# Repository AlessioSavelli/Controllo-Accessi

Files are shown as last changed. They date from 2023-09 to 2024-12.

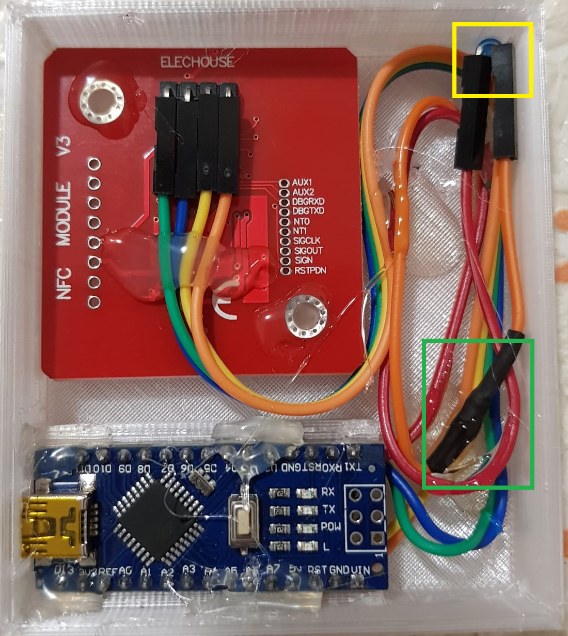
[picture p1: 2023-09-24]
Firmware/Relese/Interfaccia Software/Montaggio.png

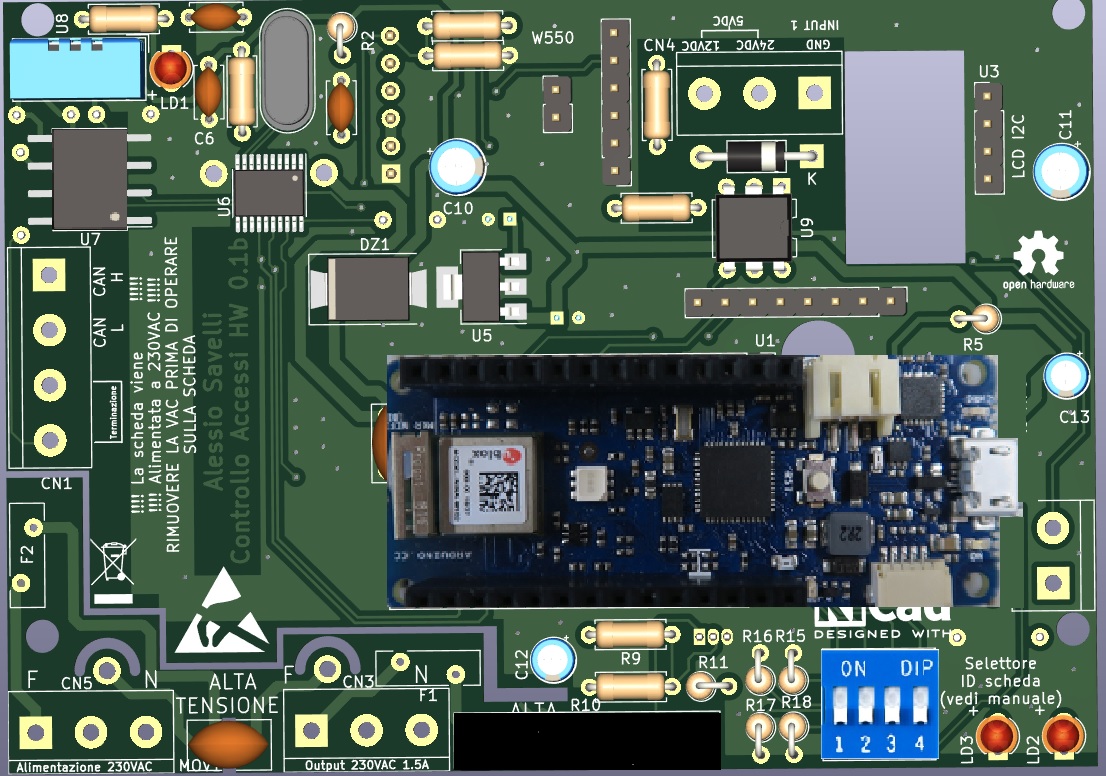
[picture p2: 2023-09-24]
Hardware/Schema Montaggio Attivatore/Immagine WhatsApp 2023-09-23 ore 09.59.53.jpg

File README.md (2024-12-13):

# Controllo Accessi  
 Controllo Accessi realizzato con arduino mkr 1010 e visual studio.

In questa sezione troverai tutti i sorgenti Hardware, Software e Firmware per creare e utilizzare il tuo allarmino.

I Firmware disponibili per Arduino MKR 1010 sono:
<table class="tg">
<thead>
  <tr>
    <th class="tg-0pky">Firmware</th>
  </tr>
</thead>
<tbody>
  <tr>
    <td class="tg-0pky">V1.0</td>
  </tr>
</tbody>
</table>
  
I Software disponibili :
  <table class="tg">
<thead>
  <tr>
    <th class="tg-0lax">Software</th>
    <th class="tg-0pky">Testato su</th>
  </tr>
</thead>
<tbody>
  <tr>
    <td class="tg-0lax">V1.0</td>
    <td class="tg-0pky">Win10 64-bit, Win 11 64-bit</td>
  </tr>
</tbody>
</table>
  
Gli Hardware disponibili :
<table class="tg">
<thead>
  <tr>
    <td class="tg-0lax">Controllo Accessi Main Board</td>
    <td class="tg-0pky">Interfaccia di scrittura badge con Arduino Mini</td>
  </tr>
</thead>
</table>

<a href="https://github.com/AlessioSavelli">Datasheet non acnora disponibile.</a>
----------------------------------------------------------
Licenza MIT
Copyright (c) 2022 Alessio Savelli

Con la presente si concede, a chiunque ottenga una copia di questo software e dei file di documentazione associati (il "Software"), l'autorizzazione a usare gratuitamente il Software senza alcuna limitazione, compresi i diritti di usare, copiare, modificare, unire, pubblicare, distribuire, cedere in sottolicenza e/o vendere copie del Software, nonché di permettere ai soggetti cui il Software è fornito di fare altrettanto, alle seguenti condizioni:

L'avviso di copyright indicato sopra e questo avviso di autorizzazione devono essere inclusi in ogni copia o parte sostanziale del Software.

IL SOFTWARE VIENE FORNITO "COSÌ COM'È", SENZA GARANZIE DI ALCUN TIPO, ESPLICITE O IMPLICITE, IVI INCLUSE, IN VIA ESEMPLIFICATIVA, LE GARANZIE DI COMMERCIABILITÀ, IDONEITÀ A UN FINE PARTICOLARE E NON VIOLAZIONE DEI DIRITTI ALTRUI. IN NESSUN CASO GLI AUTORI O I TITOLARI DEL COPYRIGHT SARANNO RESPONSABILI PER QUALSIASI RECLAMO, DANNO O ALTRO TIPO DI RESPONSABILITÀ, A SEGUITO DI AZIONE CONTRATTUALE, ILLECITO O ALTRO, DERIVANTE DA O IN CONNESSIONE AL SOFTWARE, AL SUO UTILIZZO O AD ALTRE OPERAZIONI CON LO STESSO.
--------------------------------------------------------------
Licenza MIT
Copyright (c) 2022 Alessio Savelli

Con la presente si concede, a chiunque ottenga una copia di questo hardware e dei file di documentazione associati (all "Hardware"), l'autorizzazione a usare gratuitamente l'hardware senza alcuna limitazione, compresi i diritti di usare, copiare, modificare, unire, pubblicare, distribuire, cedere in sottolicenza e/o vendere copie dell'hardware, nonché di permettere ai soggetti il cui hardware è fornito di fare altrettanto, alle seguenti condizioni:

L'avviso di copyright indicato sopra e questo avviso di autorizzazione devono essere inclusi in ogni copia o parte sostanziale dell'hardware.

L'HARDWARE VIENE FORNITO "COSÌ COM'È", SENZA GARANZIE DI ALCUN TIPO, ESPLICITE O IMPLICITE, IVI INCLUSE, IN VIA ESEMPLIFICATIVA, LE GARANZIE DI COMMERCIABILITÀ, IDONEITÀ A UN FINE PARTICOLARE E NON VIOLAZIONE DEI DIRITTI ALTRUI. IN NESSUN CASO GLI AUTORI O I TITOLARI DEL COPYRIGHT SARANNO RESPONSABILI PER QUALSIASI RECLAMO, DANNO O ALTRO TIPO DI RESPONSABILITÀ, A SEGUITO DI AZIONE CONTRATTUALE, ILLECITO O ALTRO, DERIVANTE DA O IN CONNESSIONE DELL'HARDWARE, AL SUO UTILIZZO O AD ALTRE OPERAZIONI CON LO STESSO.

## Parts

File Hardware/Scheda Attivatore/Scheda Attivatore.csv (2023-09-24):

Source: | D:\Desktop\Elettronica IN\Controllo Accessi\Hardware\Scheda Attivatore\Scheda Attivatore.kicad_sch
Date: | 15/05/2023 20:39:04
Tool: | Eeschema 7.0.1
Generator: | C:\Program Files\KiCad\7.0\bin\scripting\plugins/bom_csv_grouped_by_value.py
Component Count: | 74
Collated Components:
Item | Qty | Reference(s) | Value | LibPart | Footprint | Datasheet | DNP
1 | 1 | BZ1 | Buzzer | Device:Buzzer | Buzzer_Beeper:MagneticBuzzer_ProSignal_ABI-010-RC | ~
2 | 2 | C1, C2 | 1uF | Device:C_Polarized | Capacitor_THT:CP_Radial_D4.0mm_P2.00mm | ~
3 | 4 | C3, C6, C7, C8 | 100nF | Device:C | Capacitor_THT:C_Disc_D4.7mm_W2.5mm_P5.00mm | ~
4 | 2 | C4, C5 | 22pF | Device:C | Capacitor_THT:C_Disc_D4.7mm_W2.5mm_P5.00mm | ~
5 | 1 | C9 | 1uF 50V | Device:C | Capacitor_THT:C_Disc_D7.0mm_W2.5mm_P5.00mm | ~
6 | 2 | C10, C11 | 100uF | Device:C_Polarized | Capacitor_THT:CP_Radial_D5.0mm_P2.00mm | ~
7 | 2 | C12, C13 | 10uF | Device:C_Polarized | Capacitor_THT:CP_Radial_D4.0mm_P2.00mm | ~
8 | 1 | CN1 | CAN_OUT | Connector_Generic:Conn_01x04 | TerminalBlock:TerminalBlock_bornier-4_P5.08mm | ~
9 | 1 | CN2 | Tamper | Connector_Generic:Conn_01x02 | TerminalBlock:TerminalBlock_bornier-2_P5.08mm | ~
10 | 1 | CN3 | Rele' AC | Connector:Screw_Terminal_01x03 | TerminalBlock:TerminalBlock_bornier-3_P5.08mm | ~
11 | 1 | CN4 | INPUT | Connector:Screw_Terminal_01x03 | TerminalBlock:TerminalBlock_bornier-3_P5.08mm | ~
12 | 1 | CN5 | Supply AC | Connector:Screw_Terminal_01x03 | TerminalBlock:TerminalBlock_bornier-3_P5.08mm | ~
13 | 1 | D1 | 1N4007 | Diode:1N4007 | Diode_THT:D_DO-41_SOD81_P10.16mm_Horizontal | http://www.vishay.com/docs/88503/1n4001.pdf
14 | 1 | DZ1 | SMBJ7.0A | Device:D_Zener | Diode_SMD:D_SMB-SMC_Universal_Handsoldering | ~
15 | 2 | F1, F2 | 2A | Device:Fuse | Fuse:Fuse_Bourns_MF-RHT200 | https://it.rs-online.com/web/p/fusibili-non-ripristinabili/9113540
16 | 2 | LD1, LD2 | Verde | Device:LED | LED_THT:LED_D3.0mm | ~
17 | 1 | LD3 | Rosso | Device:LED | LED_THT:LED_D3.0mm | ~
18 | 1 | MOV1 | S14K300 | Device:Polyfuse | Capacitor_THT:C_Disc_D7.5mm_W4.4mm_P5.00mm | ~
19 | 1 | R1 | 100k | Device:R | Resistor_THT:R_Axial_DIN0207_L6.3mm_D2.5mm_P7.62mm_Horizontal | ~
20 | 5 | R2, R15, R16, R17, R18 | 100k | Device:R | Resistor_THT:R_Axial_DIN0207_L6.3mm_D2.5mm_P2.54mm_Vertical | ~
21 | 1 | R3 | 120 | Device:R | Resistor_THT:R_Axial_DIN0207_L6.3mm_D2.5mm_P7.62mm_Horizontal | ~
22 | 6 | R4, R6, R9, R19, R20, R22 | 470 | Device:R | Resistor_THT:R_Axial_DIN0207_L6.3mm_D2.5mm_P7.62mm_Horizontal | ~
23 | 1 | R5 | 120 | Device:R | Resistor_THT:R_Axial_DIN0207_L6.3mm_D2.5mm_P2.54mm_Vertical | ~
24 | 4 | R7, R8, R10, R12 | 100K | Device:R | Resistor_THT:R_Axial_DIN0207_L6.3mm_D2.5mm_P7.62mm_Horizontal | ~
25 | 1 | R11 | 330 | Device:R | Resistor_THT:R_Axial_DIN0207_L6.3mm_D2.5mm_P2.54mm_Vertical | ~
26 | 1 | R13 | 1.2K | Device:R | Resistor_THT:R_Axial_DIN0207_L6.3mm_D2.5mm_P7.62mm_Horizontal | ~
27 | 1 | R14 | 2.7K | Device:R | Resistor_THT:R_Axial_DIN0207_L6.3mm_D2.5mm_P7.62mm_Horizontal | ~
28 | 1 | R21 | 1K | Device:R | Resistor_THT:R_Axial_DIN0207_L6.3mm_D2.5mm_P7.62mm_Horizontal | ~
29 | 4 | R23, R24, R25, R26 | 10K | Device:R | Resistor_THT:R_Axial_DIN0207_L6.3mm_D2.5mm_P7.62mm_Horizontal | ~
30 | 1 | RL1 | G3MB-20P | Relay_SolidState:S102S01 | Custom:G3MB | http://www.sharp-world.com/products/device/lineup/data/pdf/datasheet/s102s01_e.pdf
31 | 1 | SW1 | DIP x04 | Switch:SW_DIP_x04 | Package_DIP:DIP-8_W7.62mm_Socket | ~
32 | 2 | T1, T2 | BC546 | Transistor_BJT:BC546 | Package_TO_SOT_THT:TO-92_Inline | https://www.onsemi.com/pub/Collateral/BC550-D.pdf
33 | 2 | T3, T4 | BSS123 | Transistor_FET:BSS123 | Package_TO_SOT_SMD:SOT-23 | http://www.diodes.com/assets/Datasheets/ds30366.pdf
34 | 1 | U1 | Left | Connector_Generic:Conn_01x14 | Connector_PinHeader_2.54mm:PinHeader_1x14_P2.54mm_Vertical | ~
35 | 1 | U1_1 | Right | Connector_Generic:Conn_01x14 | Connector_PinHeader_2.54mm:PinHeader_1x14_P2.54mm_Vertical | ~
36 | 1 | U2 | W5500 | Connector_Generic:Conn_01x06 | Connector_PinHeader_2.54mm:PinHeader_1x06_P2.54mm_Vertical | ~
37 | 1 | U2_1 | W550 | Connector_Generic:Conn_01x06 | Connector_PinHeader_2.54mm:PinHeader_1x06_P2.54mm_Vertical | ~
38 | 1 | U3 | I2C LCD | Connector_Generic:Conn_01x04 | Connector_PinHeader_2.54mm:PinHeader_1x04_P2.54mm_Vertical | ~
39 | 1 | U3_1 | Retro illuminazione LCD | Connector_Generic:Conn_01x02 | Connector_PinHeader_2.54mm:PinHeader_1x02_P2.54mm_Vertical | ~
40 | 1 | U4 | Modulo NFC | Connector_Generic:Conn_01x04 | Connector_PinHeader_2.54mm:PinHeader_1x04_P2.54mm_Vertical | ~
41 | 1 | U4_1 | Modulo NFC | Connector_Generic:Conn_01x08 | Connector_PinHeader_2.54mm:PinHeader_1x08_P2.54mm_Vertical | ~
42 | 1 | U5 | TC1262-25 | Regulator_Linear:TC1262-25 | Package_TO_SOT_SMD:SOT-223-3_TabPin2 | http://ww1.microchip.com/downloads/en/DeviceDoc/21373C.pdf
43 | 1 | U6 | MCP2515-xST | Interface_CAN_LIN:MCP2515-xST | Package_SO:TSSOP-20_4.4x6.5mm_P0.65mm | http://ww1.microchip.com/downloads/en/DeviceDoc/21801e.pdf
44 | 1 | U7 | ISO1050DUB | Interface_CAN_LIN:ISO1050DUB | Package_SO:SOP-8_6.62x9.15mm_P2.54mm | http://www.ti.com/lit/ds/symlink/iso1050.pdf
45 | 1 | U8 | ROE 5V-5V | Custom:DCDC_ISOLATED | Sensor:Aosong_DHT11_5.5x12.0_P2.54mm
46 | 1 | U9 | 4N25 | Isolator:4N25 | Package_DIP:DIP-6_W7.62mm | https://www.vishay.com/docs/83725/4n25.pdf
47 | 1 | U10 | AC-DC | Custom:AC-DC | Custom:LDE10-20Bxx | https://it.rs-online.com/web/p/alimentatori-switching/1812115
48 | 1 | Y2 | 8MHz | Device:Crystal | Crystal:Crystal_HC49-4H_Vertical | ~

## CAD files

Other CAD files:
Hardware/Schema Montaggio Attivatore/Alessio_attivatore.dwg

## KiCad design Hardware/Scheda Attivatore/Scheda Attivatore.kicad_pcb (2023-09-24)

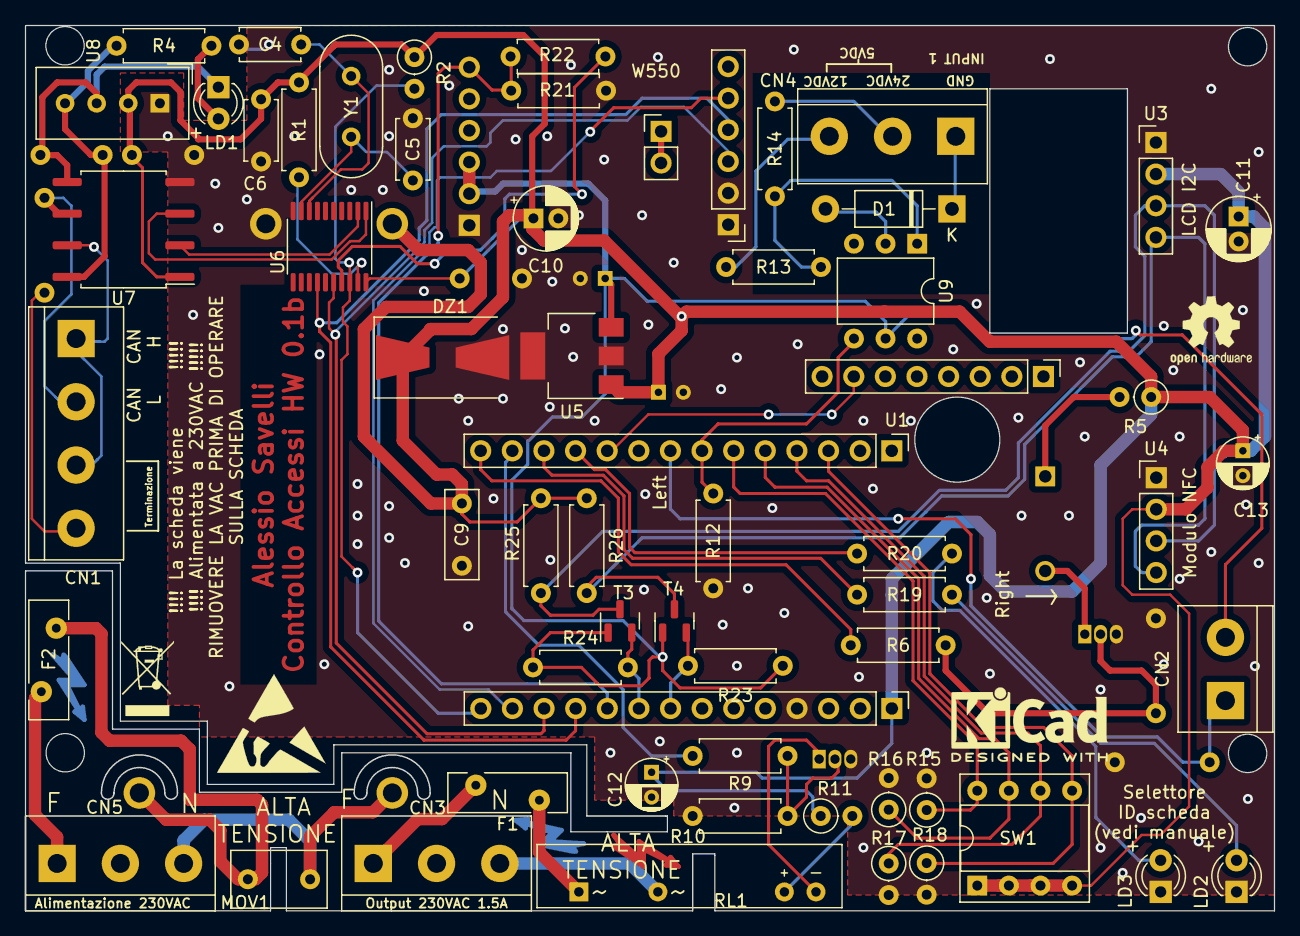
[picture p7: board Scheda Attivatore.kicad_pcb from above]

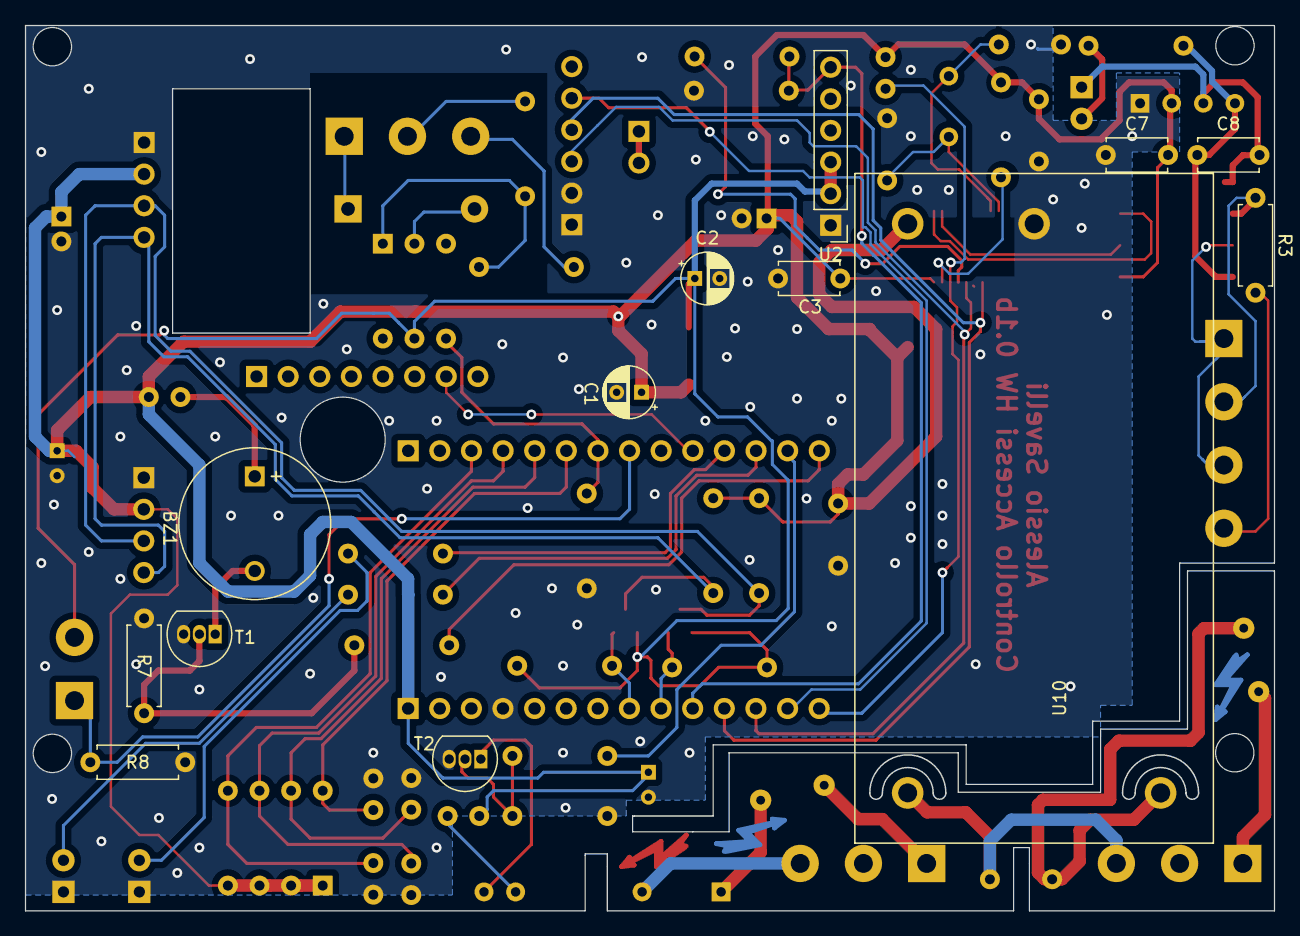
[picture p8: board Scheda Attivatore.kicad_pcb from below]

Board: 2 copper layers, 100.3 x 71.1 mm, 74 parts (13 on the bottom side), 55 nets.

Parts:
BZ1: Buzzer; MagneticBuzzer_ProSignal_ABI-010-RC
C1, C2: 1uF; CP_Radial_D4.0mm_P2.00mm
C3, C6, C7, C8: 100nF; C_Disc_D4.7mm_W2.5mm_P5.00mm
C4, C5: 22pF; C_Disc_D4.7mm_W2.5mm_P5.00mm
C9: 1uF 50V; C_Disc_D7.0mm_W2.5mm_P5.00mm
C10, C11: 100uF; CP_Radial_D5.0mm_P2.00mm
C12, C13: 10uF; CP_Radial_D4.0mm_P2.00mm
CN1: CAN_OUT; TerminalBlock_bornier-4_P5.08mm
CN2: Tamper; TerminalBlock_bornier-2_P5.08mm
CN3: Rele' AC; TerminalBlock_bornier-3_P5.08mm
CN4: INPUT; TerminalBlock_bornier-3_P5.08mm
CN5: Supply AC; TerminalBlock_bornier-3_P5.08mm
D1: 1N4007; D_DO-41_SOD81_P10.16mm_Horizontal
DZ1: SMBJ7.0A; D_SMB-SMC_Universal_Handsoldering
F1, F2: 2A; Fuse_Bourns_MF-RHT200
LD1, LD2: Verde; LED_D3.0mm
LD3: Rosso; LED_D3.0mm
MOV1: S14K300; C_Disc_D7.5mm_W4.4mm_P5.00mm
R1: 100k; R_Axial_DIN0207_L6.3mm_D2.5mm_P7.62mm_Horizontal
R2, R15, R16, R17, R18: 100k; R_Axial_DIN0207_L6.3mm_D2.5mm_P2.54mm_Vertical
R3: 120; R_Axial_DIN0207_L6.3mm_D2.5mm_P7.62mm_Horizontal
R4, R6, R9, R19, R20, R22: 470; R_Axial_DIN0207_L6.3mm_D2.5mm_P7.62mm_Horizontal
R5: 120; R_Axial_DIN0207_L6.3mm_D2.5mm_P2.54mm_Vertical
R7, R8, R10, R12: 100K; R_Axial_DIN0207_L6.3mm_D2.5mm_P7.62mm_Horizontal
R11: 330; R_Axial_DIN0207_L6.3mm_D2.5mm_P2.54mm_Vertical
R13: 1.2K; R_Axial_DIN0207_L6.3mm_D2.5mm_P7.62mm_Horizontal
R14: 2.7K; R_Axial_DIN0207_L6.3mm_D2.5mm_P7.62mm_Horizontal
R21: 1K; R_Axial_DIN0207_L6.3mm_D2.5mm_P7.62mm_Horizontal
R23, R24, R25, R26: 10K; R_Axial_DIN0207_L6.3mm_D2.5mm_P7.62mm_Horizontal
RL1: G3MB-20P; G3MB
SW1: DIP x04; DIP-8_W7.62mm_Socket
T1, T2: BC546; TO-92_Inline
T3, T4: BSS123; SOT-23
U1: Left; PinHeader_1x14_P2.54mm_Vertical
U1_1: Right; PinHeader_1x14_P2.54mm_Vertical
U2: W5500; PinHeader_1x06_P2.54mm_Vertical
U2_1: W550; PinHeader_1x06_P2.54mm_Vertical
U3: I2C LCD; PinHeader_1x04_P2.54mm_Vertical
U3_1: Retro illuminazione LCD; PinHeader_1x02_P2.54mm_Vertical
U4: Modulo NFC; PinHeader_1x04_P2.54mm_Vertical
U4_1: Modulo NFC; PinHeader_1x08_P2.54mm_Vertical
U5: TC1262-25; SOT-223-3_TabPin2
U6: MCP2515-xST; TSSOP-20_4.4x6.5mm_P0.65mm
U7: ISO1050DUB; SOP-8_6.62x9.15mm_P2.54mm
U8: ROE 5V-5V; Aosong_DHT11_5.5x12.0_P2.54mm
U9: 4N25; DIP-6_W7.62mm
U10: AC-DC; LDE10-20Bxx
Y1: 8MHz; Crystal_HC49-4H_Vertical

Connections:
+3.3V: C2.1, CN2.2, R23.1, R24.1, T3.1 (G), T4.1 (G), U2.2, U2.3, U5.3 (VO), U9.5
+5C: C8.1, R4.1, U7.8 (VCC2), U8.4 (+Vout)
+5V: C1.1, C3.2, C6.2, C7.2, C9.2, C10.1, C11.1, C12.1, C13.1, DZ1.1 (K), R1.1, R2.1, R5.1, R11.1, R25.1, R26.1, SW1.1, SW1.2, SW1.3, SW1.4, U1_1.1, U3.2, U4.2, U5.1 (VI), U6.20 (VDD), U7.1 (VCC1), U8.2 (+Vin), U10.4
A1: R15.1, SW1.5, U1.3
A2: R16.1, SW1.6, U1.4
A3: R17.1, SW1.7, U1.5
A4: R18.1, SW1.8, U1.6
A5: R12.2, U1.7, U9.4
A6: CN2.1, R8.1, U1.8
BUZZER: R6.1, U1.14
CS_CAN: R2.2, U1_1.14, U6.18 (~CS)
CS_ETH: U1_1.13, U2_1.5
D1: U1.10, U4_1.7
D2: R20.1, U1.11
D3: R19.1, U1.12
D4: R9.1, U1.13
D8: U1_1.12, U2_1.3, U6.16 (SI)
D9: U1_1.11, U2_1.4, U6.14 (SCK)
D10: R21.1, R22.1, U1_1.10, U2.6
D11: R24.2, T3.2 (S), U1_1.9
D12: R23.2, T4.2 (S), U1_1.8
GND: C1.2, C2.2, C3.1, C4.1, C5.2, C6.1, C7.1, C9.1, C10.2, C11.2, C12.2, C13.2, DZ1.2 (A), LD2.1 (K), LD3.1 (K), R7.1, R8.2, R10.1, R12.1, R15.2, R16.2, R17.2, R18.2, R21.2, T1.3 (E), T2.3 (E), U1_1.4, U2.1, U2_1.1, U2_1.2, U3.1, U4.1, U5.2 (GND), U6.10 (VSS), U7.4 (GND1), U8.1 (-Vin), U10.3
GNDD: C8.2, LD1.1 (K), U7.5 (GND2), U8.3 (-Vout)
unnamed: BZ1.2 (+), T1.1 (C)
unnamed: BZ1.1 (-), R5.2
unnamed: CN1.1, CN1.3, U7.7 (CANH)
unnamed: CN1.2, R3.1, U7.6 (CANL)
unnamed: CN1.4, R3.2
unnamed: CN3.1, F1.2
unnamed: CN3.3, RL1.2
unnamed: CN4.1, D1.1 (K)
unnamed: CN4.2, R14.1
unnamed: CN4.3, R13.1
unnamed: CN5.1, F2.1
unnamed: CN5.3, MOV1.2, U10.2
unnamed: D1.2 (A), U9.2
unnamed: F1.1, RL1.1
unnamed: LD1.2 (A), R4.2
unnamed: LD2.2 (A), R19.2
unnamed: LD3.2 (A), R20.2
unnamed: R11.2, RL1.3
unnamed: R13.2, R14.2, U9.1
unnamed: R6.2, R7.2, T1.2 (B)
unnamed: R9.2, R10.2, T2.2 (B)
unnamed: RL1.4, T2.1 (C)
unnamed: U3_1.1, U3_1.2
unnamed: C5.1, U6.9 (OSC1), Y1.1
unnamed: C4.2, U6.8 (OSC2), Y1.2
unnamed: U6.2 (RXCAN), U7.2 (RXD)
unnamed: R22.2, U6.17 (SO)
unnamed: U6.1 (TXCAN), U7.3 (TXD)
unnamed: R1.2, U6.19 (~RESET)
unnamed: F2.2, MOV1.1, U10.1
SCL: R26.2, T4.3 (D), U3.4, U4.4
SDA: R25.2, T3.3 (D), U3.3, U4.3

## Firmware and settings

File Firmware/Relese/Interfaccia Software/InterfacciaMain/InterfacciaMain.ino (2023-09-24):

/*
Licenza MIT (Massachusetts Institute of Technology)

Copyright (c) 2023  Alessio Savelli

È concesso in licenza gratuitamente a chiunque ottenga una copia di questo software e dei file di documentazione associati (il "Software"), di trattare il Software senza restrizioni, compresi, ma non limitati ai diritti di utilizzo, copia, modifica, fusione, pubblicazione, distribuzione, sublicenza e/o vendita delle copie del Software e di consentire alle persone a cui il Software è fornito di farlo, a condizione che le seguenti condizioni siano soddisfatte:

Il testo completo della Licenza MIT (in inglese):
MIT License

Copyright (c) 2023 Alessio Savelli

Permission is hereby granted, free of charge, to any person obtaining a copy of this software and associated documentation files (the "Software"), to deal in the Software without restriction, including without limitation the rights to use, copy, modify, merge, publish, distribute, sublicense, and/or sell copies of the Software, and to permit persons to whom the Software is furnished to do so, subject to the following conditions:

The above copyright notice and this permission notice shall be included in all copies or substantial portions of the Software.

THE SOFTWARE IS PROVIDED "AS IS", WITHOUT WARRANTY OF ANY KIND, EXPRESS OR IMPLIED, INCLUDING BUT NOT LIMITED TO THE WARRANTIES OF MERCHANTABILITY, FITNESS FOR A PARTICULAR PURPOSE AND NONINFRINGEMENT. IN NO EVENT SHALL THE AUTHORS OR COPYRIGHT HOLDERS BE LIABLE FOR ANY CLAIM, DAMAGES OR OTHER LIABILITY, WHETHER IN AN ACTION OF CONTRACT, TORT OR OTHERWISE, ARISING FROM, OUT OF OR IN CONNECTION WITH THE SOFTWARE OR THE USE OR OTHER DEALINGS IN THE SOFTWARE.


*/

#include <SoftwareSerial.h>
#include "PN532_SWHSU.h"
#include "PN532.h"

#define STD_KEYA 0xFF, 0xFF, 0xFF, 0xFF, 0xFF, 0xFF  //Sono le chiavi per accedere al settore da modificare
#define STD_KEYB 0xFF, 0xFF, 0xFF, 0xFF, 0xFF, 0xFF  //Sono le chiavi per accedere al settore da modificare

#define ACCESS_BITS 0xFF, 0x07, 0x80

//Qualora dopo aver popolato il settore si volessero cambiare le chiavi vanno specificate qui
#define NEW_STD_KEYA STD_KEYA
#define NEW_STD_KEYB STD_KEYB



#define CALCULATE_BLOCK_FROM_SECTOR(x) (x * 4)
#define BLOCK_INDEX_FROM_SECTOR(sector, block) (CALCULATE_BLOCK_FROM_SECTOR(sector) + block)

unsigned long timer0 = 0;
unsigned long timer1 = 0;
unsigned long timer2 = 0;
const byte rxPin = 2;
const byte txPin = 3;


uint8_t uid[] = { 0, 0, 0, 0, 0, 0, 0 };  // Buffer to store the returned UID
uint8_t uidLength;                        // Length of the UID (4 or 7 bytes depending on ISO14443A card type)

SoftwareSerial SWSerial(txPin, rxPin);

PN532_SWHSU pn532swhsu(SWSerial);
PN532 nfc(pn532swhsu);

enum SERIAL_HEADER {
  IDLE_WAITING_HEADER = 0x00,
  ERROR_MODULE = 0x01,
  VERS_MODULE = 0x02,
  WAIT_BADGE = 0x03,
  PRESENT_BADGE = 0x04,
  GET_UID_BADGE = 0x05,
  WRITE_BADGE = 0x06,
  SUCCESS_WRITE_BADGE = 0x07,

  //WritingBadgeProcess
  WRITE_BADGE_GET_LENGHT = 0xA0,
  WRITE_BADGE_GET_LENGHT_ERROR = 0xA1,
  WRITE_BADGE_GET_BRENDSECTOR = 0xA2,
  WRITE_BADGE_GET_LINE1 = 0xA3,
  WRITE_BADGE_GET_LINE2 = 0xA4,
  WRITE_BADGE_PUSHDATA = 0xA5,
  //----



  ERROR_WRITE_BADGE_UID = 0xF1,
  ERROR_WRITE_BADGE_AUTH1 = 0xF2,
  ERROR_WRITE_BADGE_AUTH2 = 0xF3,
  ERROR_WRITE_BADGE_BRENDSECTOR = 0xF4,
  ERROR_WRITE_BADGE_LINE1 = 0xF5,
  ERROR_WRITE_BADGE_LINE2 = 0xF6,
  ERROR_WRITE_BADGE_TRAILER = 0xF7,

  ERROR_FRAME_LENGHT = 0xFD,
  ERROR_FRAME = 0xFE,
  END_COMUNICATE = 0xFF
};
int serial_header_index = IDLE_WAITING_HEADER;


enum STATE {
  IDLE,
  WAITING_FOR_HEADER,
  PROCESSING_COMMAND
};

STATE state = IDLE;
byte header;


const int BUFFER_SIZE = 64 * 2;  // Dimensione del buffer per la lettura dei dati
byte buffer[BUFFER_SIZE];
int bufferIndex_w = 0;
int bufferIndex_r = 0;
//----Definsico le macro per i buffer circolare---
#define CIRC_BUFFER_MULTISCROLL(index, scroll, maxItem) (index = (index + scroll) % maxItem)
#define CIRC_BUFFER_ONESCROLL(index, maxItem) (CIRC_BUFFER_MULTISCROLL(index, 1, maxItem))
#define REMOVE_FROM_INDEX(index, len) (index -= len)
#define ADD_TO_INDEX(index, len) (index += len)
#define NEED_TO_READ_SERIAL(read_index, write_index) (read_index != write_index)
//------


uint32_t versiondata = 0x00;

void read_serial();
void processing_payload();

void waiting_badge();
byte writing_badge(uint8_t brendSector[16], uint8_t b0_ln1[16], uint8_t b0_ln2[16], int SECTOR_TO_WRITE);
byte CRC8(const byte *data, byte len);

void setup() {
  pinMode(13, OUTPUT);
  // Inizializza le porte seriali
  Serial.begin(115200);  // Inizializza la porta seriale predefinita
  nfc.begin();
  versiondata = nfc.getFirmwareVersion();
  if (!versiondata) {
    while (true) {
      Serial.write(ERROR_MODULE);
      delay(250);
    }
  }
  // Configure board to read RFID tags
  nfc.SAMConfig();

  timer1 = millis();
  timer2 = millis();
}

void loop() {
  if (serial_header_index == IDLE_WAITING_HEADER) {
    if (millis() - timer2 < 30 * 1000) {  //dall'ultimo evento lampeggia per ulteriori 10s dopo di che non lo fa piu'
      //se arduino e' in modalita idle fa un blink per indicare che il sistema e' accesso
      if (millis() - timer1 >= 2000) {
        digitalWrite(13, HIGH);
        timer1 = millis();
      } else if (millis() - timer1 >= 100 && millis() - timer1 <= 130) {
        digitalWrite(13, LOW);
      }

    } else {
      digitalWrite(13, LOW);
      timer1 = millis();
    }
  } else if (millis() - timer0 >= 2000) {
    digitalWrite(13, LOW);
  }
  read_serial();  //Legge la seriale e la salva in un buffer circolare. legge in byte per volta dalla seriale
  //dopo aver letto un byte si sposta nel loop che lo processera'
  if (NEED_TO_READ_SERIAL(bufferIndex_w, bufferIndex_r)) {  //se ci sono dati da leggere nel buffer esegue l'operazione
    processing_payload();                                   //legge i payload ricevuti e li processa
  }
}
void read_serial() {
  if (Serial.available()) {
    buffer[bufferIndex_w] = Serial.read();
    CIRC_BUFFER_ONESCROLL(bufferIndex_w, BUFFER_SIZE);  //sponta l'indice di scrittura
  }
}
void processing_payload() {

  static byte sector_id;
  static byte lengt_payload = 0;
  static byte index_payload = 0;

  //  Gli ultimi 3 byte sono il CRC         !CRCLN1!CRCLN2!CRC!
  static uint8_t brendSector[16]{ 0 };
  static uint8_t b0_ln1[16] = { 0 };
  static uint8_t b0_ln2[16] = { 0 };

  byte value = 0x00;
  if (NEED_TO_READ_SERIAL(bufferIndex_w, bufferIndex_r)) {
    value = buffer[bufferIndex_r];
    CIRC_BUFFER_ONESCROLL(bufferIndex_r, BUFFER_SIZE);
    //ogni volta che legge qualcosa resetta il timer di idle
    timer2 = millis();
  }
  switch (serial_header_index) {
    case IDLE_WAITING_HEADER:
      //Se la macchina a stati e' in idle e il valore contiene un messaggio diverso da Error Write Badge , allora lo imposta come header
      if (value != END_COMUNICATE) {
        serial_header_index = value;
      }

      break;
    //Adesso processa gli header letti
    case VERS_MODULE:
      Serial.write(VERS_MODULE);
      Serial.write(versiondata);
      Serial.write(END_COMUNICATE);
      serial_header_index = IDLE_WAITING_HEADER;
      break;
    case WAIT_BADGE:
      waiting_badge();
      Serial.write(PRESENT_BADGE);
      Serial.write(END_COMUNICATE);
      serial_header_index = IDLE_WAITING_HEADER;
      break;
    case GET_UID_BADGE:
      Serial.write(GET_UID_BADGE);
      Serial.write(uidLength);
      for (int i = 0; i < uidLength; i++) {
        Serial.write(uid[i]);
      }
      Serial.write(END_COMUNICATE);
      serial_header_index = IDLE_WAITING_HEADER;
      break;
    case WRITE_BADGE:
      sector_id = value;  //ottiene il settore dove scrivere i dati
      serial_header_index = WRITE_BADGE_GET_LENGHT;
      break;
    case WRITE_BADGE_GET_LENGHT:
      lengt_payload = value;
      //Verifica la lunghezze del pyload che sia pari a 16 byte per blocco, leggendo 3 blocchi il valore deve essere 16*3 48
      serial_header_index = WRITE_BADGE_GET_BRENDSECTOR;
      index_payload = 0;
      if (lengt_payload != 48) {  // se non corrisponde a 48 allora va in errore
        serial_header_index = WRITE_BADGE_GET_LENGHT_ERROR;
      }
      break;
    case WRITE_BADGE_GET_LENGHT_ERROR:
      //Gestisce l'errore leggendo a vuoto il payload
      index_payload++;
      if (index_payload >= (lengt_payload + 1)) {  //a letto tutto il payload errato + l'end frame allora ritorna il messaggio di errore
        Serial.write(ERROR_FRAME_LENGHT);
        Serial.write(END_COMUNICATE);
        serial_header_index = IDLE_WAITING_HEADER;
      }
      break;
    case WRITE_BADGE_GET_BRENDSECTOR:
      //legge il payload
      brendSector[index_payload] = value;
      index_payload++;
      if (index_payload >= 16) {  // se ha letto i suoi 16 byte passa a leggere il prossimo settore
        index_payload = 0;
        serial_header_index = WRITE_BADGE_GET_LINE1;
      }
      break;
    case WRITE_BADGE_GET_LINE1:
      //legge il payload
      b0_ln1[index_payload] = value;
      index_payload++;
      if (index_payload >= 16) {  // se ha letto i suoi 16 byte passa a leggere il prossimo settore
        index_payload = 0;
        serial_header_index = WRITE_BADGE_GET_LINE2;
      }
      break;
    case WRITE_BADGE_GET_LINE2:
      //legge il payload
      b0_ln2[index_payload] = value;
      index_payload++;
      if (index_payload >= 16) {  // se ha letto i suoi 16 byte passa a leggere il prossimo settore
        index_payload = 0;
        serial_header_index = WRITE_BADGE_PUSHDATA;
      }
      break;
    case WRITE_BADGE_PUSHDATA:  //Attende l'end comunicate per scrivere i dati nel badge
      if (value == END_COMUNICATE) {
        Serial.write(writing_badge(brendSector, b0_ln1, b0_ln2, sector_id));
        Serial.write(END_COMUNICATE);
        serial_header_index = IDLE_WAITING_HEADER;
      }
      break;
    default:  //nel caso in cui non conosce l'header o non sa cosa fare, fa l'echo dei dati che riceve
      Serial.write(ERROR_FRAME);
      Serial.write(END_COMUNICATE);
      serial_header_index = IDLE_WAITING_HEADER;
      break;
  }
}
byte writing_badge(uint8_t brendSector[16], uint8_t b0_ln1[16], uint8_t b0_ln2[16], int SECTOR_TO_WRITE) {

  digitalWrite(13, HIGH);
  uint8_t success;
  uint8_t uid[] = { 0, 0, 0, 0, 0, 0, 0 };  // Buffer to store the returned UID
  uint8_t uidLength;                        // Length of the UID (4 or 7 bytes depending on ISO14443A card type)

  success = nfc.readPassiveTargetID(PN532_MIFARE_ISO14443A, uid, &uidLength);

  if (success) {
    if (uidLength != 4) {
      digitalWrite(13, LOW);
      return ERROR_WRITE_BADGE_UID;
    }
    byte keyA[6] = { STD_KEYA };
    uint8_t sectorIndex = SECTOR_TO_WRITE * 4;  // Calculate the sector index once
    // Authenticate to the block
    success = nfc.mifareclassic_AuthenticateBlock(uid, uidLength, CALCULATE_BLOCK_FROM_SECTOR(SECTOR_TO_WRITE), 0, keyA);
    if (!success) {
      digitalWrite(13, LOW);
      return ERROR_WRITE_BADGE_AUTH2;
    }

    // Calculate and set CRC values
    brendSector[13] = CRC8(b0_ln1, 16);
    brendSector[14] = CRC8(b0_ln2, 16);
    brendSector[15] = CRC8(brendSector, 15);  // Calculate the final CRC


    success = nfc.mifareclassic_WriteDataBlock(BLOCK_INDEX_FROM_SECTOR(SECTOR_TO_WRITE, 0), brendSector);
    if (!success) {
      return ERROR_WRITE_BADGE_BRENDSECTOR;
    }
    success = nfc.mifareclassic_WriteDataBlock(BLOCK_INDEX_FROM_SECTOR(SECTOR_TO_WRITE, 1), b0_ln1);
    if (!success) {
      return ERROR_WRITE_BADGE_LINE1;
    }
    success = nfc.mifareclassic_WriteDataBlock(BLOCK_INDEX_FROM_SECTOR(SECTOR_TO_WRITE, 2), b0_ln2);
    if (!success) {
      return ERROR_WRITE_BADGE_LINE2;
    }
    uint8_t magicLine[16]{ NEW_STD_KEYA, ACCESS_BITS, 0x69, NEW_STD_KEYB };
    success = nfc.mifareclassic_WriteDataBlock(BLOCK_INDEX_FROM_SECTOR(SECTOR_TO_WRITE, 3), magicLine);  //Settore delle chiavi
    if (!success) {
      return ERROR_WRITE_BADGE_TRAILER;
    }
    timer0 = millis();
    return SUCCESS_WRITE_BADGE;
  }
  return ERROR_WRITE_BADGE_AUTH1;
}

void waiting_badge() {
  digitalWrite(13, HIGH);
  while (!nfc.readPassiveTargetID(PN532_MIFARE_ISO14443A, &uid[0], &uidLength)) {
    delay(1000);
    // Puoi aggiungere un ritardo breve qui se desideri evitare di sovraccaricare il modulo NFC
  }
  digitalWrite(13, LOW);
}
byte CRC8(const byte *data, byte len) {
  byte crc = 0x00;
  while (len--) {
    byte extract = *data++;
    for (byte tempI = 8; tempI; tempI--) {
      byte sum = (crc ^ extract) & 0x01;
      crc >>= 1;
      if (sum) {
        crc ^= 0x8C;
      }
      extract >>= 1;
    }
  }
  return crc;
}

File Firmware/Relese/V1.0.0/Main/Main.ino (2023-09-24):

/*
   Titolo   : NFC Access Control - Elettronica IN
   Hardware : Arduino nano
   Ver      : 1.0V
   Data     : 22/09/2023
   Autore   : Alessio Savelli - Futura Group
Licenza MIT (Massachusetts Institute of Technology)

Copyright (c) 2023  Alessio Savelli

È concesso in licenza gratuitamente a chiunque ottenga una copia di questo software e dei file di documentazione associati (il "Software"), di trattare il Software senza restrizioni, compresi, ma non limitati ai diritti di utilizzo, copia, modifica, fusione, pubblicazione, distribuzione, sublicenza e/o vendita delle copie del Software e di consentire alle persone a cui il Software è fornito di farlo, a condizione che le seguenti condizioni siano soddisfatte:

Il testo completo della Licenza MIT (in inglese):
MIT License

Copyright (c) 2023 Alessio Savelli

Permission is hereby granted, free of charge, to any person obtaining a copy of this software and associated documentation files (the "Software"), to deal in the Software without restriction, including without limitation the rights to use, copy, modify, merge, publish, distribute, sublicense, and/or sell copies of the Software, and to permit persons to whom the Software is furnished to do so, subject to the following conditions:

The above copyright notice and this permission notice shall be included in all copies or substantial portions of the Software.

THE SOFTWARE IS PROVIDED "AS IS", WITHOUT WARRANTY OF ANY KIND, EXPRESS OR IMPLIED, INCLUDING BUT NOT LIMITED TO THE WARRANTIES OF MERCHANTABILITY, FITNESS FOR A PARTICULAR PURPOSE AND NONINFRINGEMENT. IN NO EVENT SHALL THE AUTHORS OR COPYRIGHT HOLDERS BE LIABLE FOR ANY CLAIM, DAMAGES OR OTHER LIABILITY, WHETHER IN AN ACTION OF CONTRACT, TORT OR OTHERWISE, ARISING FROM, OUT OF OR IN CONNECTION WITH THE SOFTWARE OR THE USE OR OTHER DEALINGS IN THE SOFTWARE.

*/
#define DEVICE_ID switch_id
#define START_INDEX_ID 0  //Variare questo numero solo in caso in cui ci siano piu' di 16 dispositivi con lo stesso nome ma ID Diverso

#include <Scheduler.h>
#include "Macro.h"
#include "Setup.h"
#include "VALIDCARD.h"
#include "NFC.h"
#include "LCD.h"
#include "IO.h"
#include "Internet.h"
#include "mqtt.h"
#include "MY_CAN.h"

#define TERMINAL Serial  //Definisco la periferica seriale su cui fare debug
/*
   Definisco le variabili per gli stati dei componenti hardware
*/

bool nfc_status = false;
bool lcd_status = false;

/*
   Definisco le macro per lo stato dei componenti hardware
*/


#define NFC_CONNECTED nfc_status
#define LCD_CONNECTED lcd_status
//Controlla in base al programma se l'output deve essere bistable oppure no
#define IS_BISTABLE_OUTPUT(prg) ((prg == OUTPUT_TRG_EVENT_VALIDBADGE) || (prg == OUTPUT_TRG_EVENT_INVALIDBADGE) || (prg == OUTPUT_TRG_EVENT_MQTT_CONTROLLED_TRG)) ? (true) : (false)

OUTPUT_INFO my_output[3];
INPUT_INFO my_input[2];

int switch_id = 0;  //Ottiene l'id macchina impostato con gli switch

void read_badge();
void loop2();
void loop3();
void loop4();

void setup() {

  // Inizializzo la seriale
  TERMINAL.begin(115200);

  TERMINAL.print("NFC Access Controller ");
  TERMINAL.println(VERSIONE_FW);

  pinMode(DIP_SW1, INPUT);
  pinMode(DIP_SW2, INPUT);
  pinMode(DIP_SW3, INPUT);
  pinMode(DIP_SW4, INPUT);
  //Calcolo Device ID
  DEVICE_ID = (START_INDEX_ID * 16) + (digitalRead(DIP_SW1) | (digitalRead(DIP_SW2) << 1) | (digitalRead(DIP_SW3) << 2) | (digitalRead(DIP_SW4) << 3));
  TERMINAL.print("DEVICE ID =");
  TERMINAL.println(DEVICE_ID);
  delay(100);


  if (nfc_setup()) NFC_CONNECTED = true;  // imposta lo stato dell'NFC OK
  if (lcd_setup()) LCD_CONNECTED = true;  // imposta lo stato dell'LCD OK
  TERMINAL.print("Modulo NFC : ");
  TERMINAL.print((NFC_CONNECTED) ? (" trovato - ") : (" non trovato\n"));
  if (NFC_CONNECTED) nfc_print_version();  //Stampa la versione del modulo trovato

  TERMINAL.print("Modulo LCD : ");
  TERMINAL.println((LCD_CONNECTED) ? (" trovato") : (" non trovato"));
  lcd_startup_message();

  delay(100);
  //Setup pin out
  my_output[0] = io_output_setup(LED_SUCCESS, LOW, IS_BISTABLE_OUTPUT(LED_SUCCESS_EVENT), LED_SUCCESS_EVENT, TRG_MS_LED_SUCCESS_EVENT);
  my_output[1] = io_output_setup(LED_FAIL, LOW, IS_BISTABLE_OUTPUT(LED_FAIL_EVENT), LED_FAIL_EVENT, TRG_MS_LED_FAIL_EVENT);
  my_output[2] = io_output_setup(OUTPUT_RELE, LOW, IS_BISTABLE_OUTPUT(OUTPUT_EVENT), OUTPUT_EVENT, TRG_MS_OUTPUT_EVENT);

  pinMode(BUZZER_SOUND, OUTPUT);

  my_input[0] = io_input_setup(INPUT_PROG1, INPUT1_EVENT);
  my_input[1] = io_input_setup(INPUT_TAMPER, INPUT_TAMPER_EVENT);

  pinMode(IRQ_NFC, INPUT);


#ifdef CREATE_NFC_TAG
  TERMINAL.println("Pronto per la creazione del TAG");
  while (true) {  //Crea solo il TAG
    TERMINAL.println("Place your NDEF formatted Mifare Classic 1K card on the reader");
    TERMINAL.println("and press any key to continue ...");
    // Wait for user input before proceeding
    while (!TERMINAL.available())
      ;
    while (TERMINAL.available()) TERMINAL.read();
    create_nfc_tag();
    delay(100);
  }
#endif
  //Delay di benvenuto
  for (int i = 0; i < 3; i++) {
    digitalWrite(BUZZER_SOUND, HIGH);
    delay(150);
    digitalWrite(BUZZER_SOUND, LOW);
    delay(350);
  }
  digitalWrite(BUZZER_SOUND, LOW);

  Scheduler.startLoop(loop2);
  Scheduler.startLoop(loop3);
  Scheduler.startLoop(loop4);
}

void loop() {

  loop_internet();


#ifdef ENABLE_MQTT
  static unsigned long mqtt_timer0 = millis();
  if (IS_DELAYED(mqtt_timer0, 0.5 * SECONDS)) {
    mqtt_output_status(my_output);
    mqtt_input_status(my_input);
    START_TIMER(mqtt_timer0);
  }
#endif
  // IMPORTANT:
  // We must call 'yield' at a regular basis to pass
  // control to other tasks.
  yield();
}


void loop2() {
  if (NFC_CONNECTED && !EVENT_HANDLER.DISABLE_NFC) nfc_loop();
  if (LCD_CONNECTED) lcd_loop();

  if (!EVENT_HANDLER.DISABLE_NFC) read_badge();
  // IMPORTANT:
  // We must call 'yield' at a regular basis to pass
  // control to other tasks.
  yield();
}
void loop3() {
  static unsigned int index_output = 0;
  static unsigned int index_input = 0;
  //gestisco gli un output per ogni ciclo di loop
  io_output_write(&my_output[index_output]);  //Mantiene aggiornato costantemete lo stato delle uscite
  CIRC_BUFFER_ONESCROLL(index_output, 3);

  //gestisco gli un input per ogni ciclo di loop
  io_input_read(&my_input[index_input]);  //Mantiene aggiornato costantemete lo stato delle uscite
  CIRC_BUFFER_ONESCROLL(index_input, 2);
  // IMPORTANT:
  // We must call 'yield' at a regular basis to pass
  // control to other tasks.
  yield();
}
void loop4() {
#ifdef ENABLE_CAN
  loop_can(my_output, my_input);
#endif
  // IMPORTANT:
  // We must call 'yield' at a regular basis to pass
  // control to other tasks.
  yield();
}
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

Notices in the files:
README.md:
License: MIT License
